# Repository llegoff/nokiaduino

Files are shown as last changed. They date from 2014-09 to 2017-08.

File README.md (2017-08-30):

nokiaduino
==========
carte compatible Arduino équipée d'un afficheur de nokia 5110 , 
un clavier 5 touches, un lecteur de carte microSD, un convertisseur DC-DC boost
et des connecteur pour ajouter des capteurs.

*Arduino compatible board provided with a display of nokia 5110,
5 keys keyboard, a microSD card slot, a DC-DC boost converter
and connector to add sensors.*

Schemas
-------
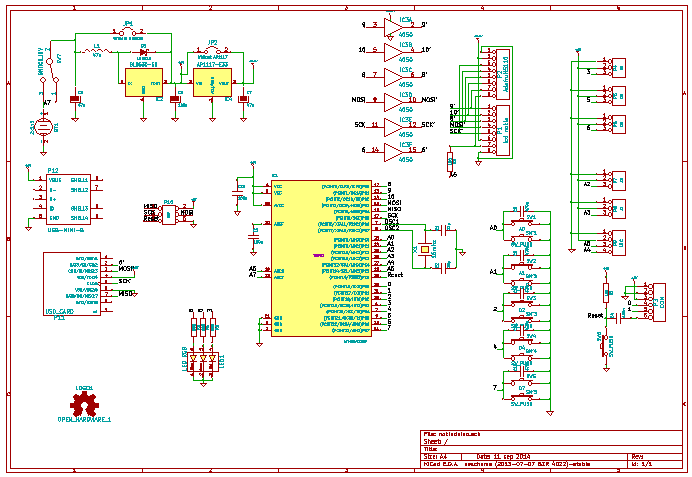
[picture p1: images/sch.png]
sch

nokiaduino.pdf

PCB
---
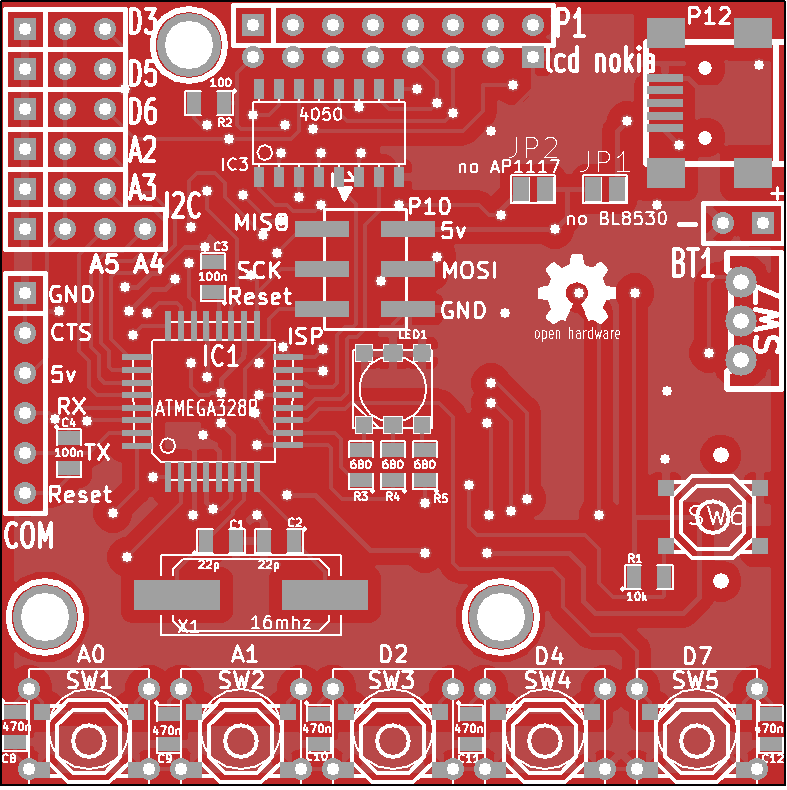
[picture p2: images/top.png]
Top

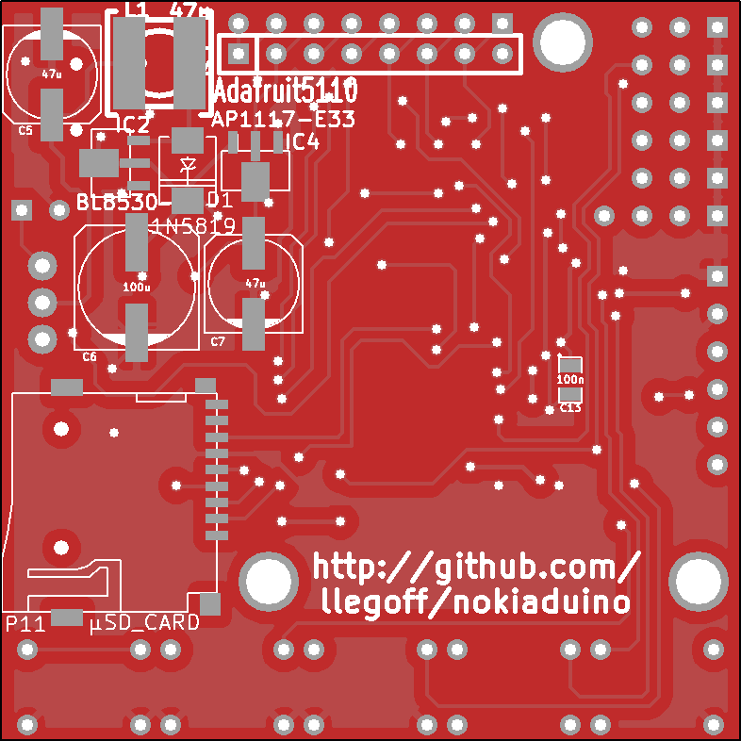
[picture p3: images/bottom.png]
Bottom


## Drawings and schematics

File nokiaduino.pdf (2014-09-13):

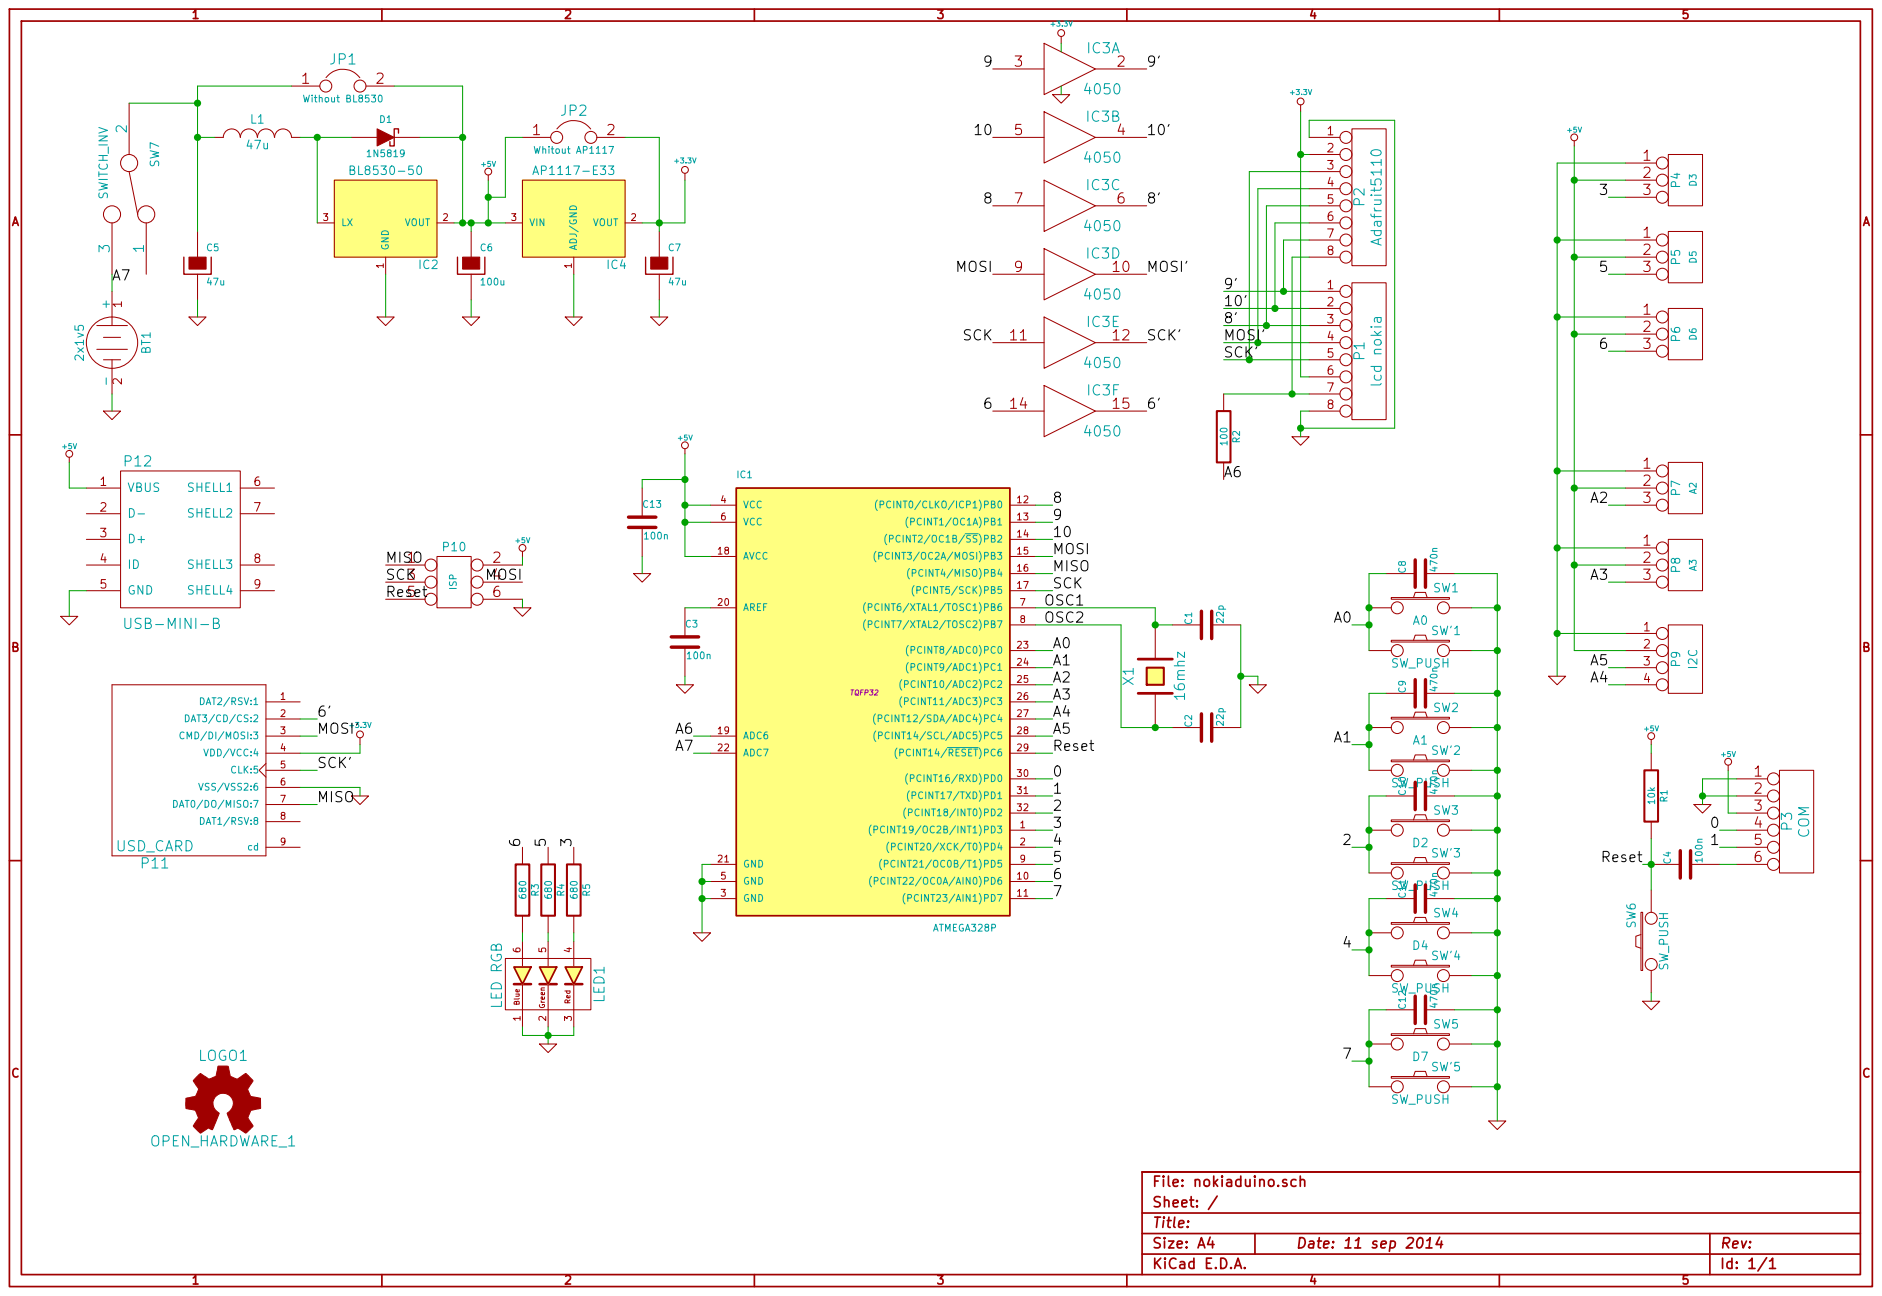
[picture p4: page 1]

Id: 1/1 Title: File: nokiaduino.sch Sheet: /

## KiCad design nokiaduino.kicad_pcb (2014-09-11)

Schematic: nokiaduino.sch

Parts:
BT1: 2x1v5
C1, C2: 22p
C3, C4, C13: 100n
C5, C7: 47u
C6: 100u
C8, C9, C10, C11, C12: 470n
D1: 1N5819
IC1: ATMEGA328P; TQFP32
IC2: BL8530-50
IC3: 4050
IC4: AP1117-E33
JP1: Without BL8530
JP2: Whitout AP1117
L1: 47u
LED1: LED RGB
LOGO1: OPEN_HARDWARE_1
P1: lcd nokia
P2: Adafruit5110
P3: COM
P4: D3
P5: D5
P6: D6
P7: A2
P8: A3
P9: I2C
P10: ISP
P11: USD_CARD
P12: USB-MINI-B
R1: 10k
R2: 100
R3, R4, R5: 680
SW1: A0
SW2: A1
SW3: D2
SW4: D4
SW5: D7
SW6: SW_PUSH
SW7: SWITCH_INV
SW'1, SW'2, SW'3, SW'4, SW'5: SW_PUSH
X1: 16mhz

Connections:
+3.3V: C7.1, IC3.1 (VCC), IC4.2 (VOUT), JP2.2, P1.6, P2.2, P11.4
+5V: C6.1, C13.1, D1.2 (K), IC1.4 (VCC), IC1.6 (VCC), IC1.18 (AVCC), IC2.2 (VOUT), IC4.3 (VIN), JP1.2, JP2.1, P3.3, P4.2 (PM), P5.2 (PM), P6.2 (PM), P7.2 (PM), P8.2 (PM), P9.2, P10.2, P12.1 (VBUS), R1.1
/0: IC1.30 ((PCINT16/RXD)PD0), P3.4
/1: IC1.31 ((PCINT17/TXD)PD1), P3.5
/2: C10.1, IC1.32 ((PCINT18/INT0)PD2), SW3.1, SW'3.1
/3: IC1.1 ((PCINT19/OC2B/INT1)PD3), P4.3, R5.1
/4: C11.1, IC1.2 ((PCINT20/XCK/T0)PD4), SW4.1, SW'4.1
/5: IC1.9 ((PCINT21/OC0B/T1)PD5), P5.3, R4.1
/6: IC1.10 ((PCINT22/OC0A/AIN0)PD6), IC3.14, P6.3, R3.1
/6': IC3.15, P11.2
/7: C12.1, IC1.11 ((PCINT23/AIN1)PD7), SW5.1, SW'5.1
/8: IC1.12 ((PCINT0/CLKO/ICP1)PB0), IC3.7
/8': IC3.6, P1.3, P2.5
/9: IC1.13 ((PCINT1/OC1A)PB1), IC3.3
/9': IC3.2, P1.1, P2.7
/10: IC1.14 ((PCINT2/OC1B/~SS~)PB2), IC3.5
/10': IC3.4, P1.2, P2.6
/A0: C8.1, IC1.23 ((PCINT8/ADC0)PC0), SW1.1, SW'1.1
/A1: C9.1, IC1.24 ((PCINT9/ADC1)PC1), SW2.1, SW'2.1
/A2: IC1.25 ((PCINT10/ADC2)PC2), P7.3
/A3: IC1.26 ((PCINT11/ADC3)PC3), P8.3
/A4: IC1.27 ((PCINT12/SDA/ADC4)PC4), P9.4
/A5: IC1.28 ((PCINT14/SCL/ADC5)PC5), P9.3
/A6: IC1.19 (ADC6), R2.2
/A7: BT1.1 (+), IC1.22 (ADC7), SW7.3
/MISO: IC1.16 ((PCINT4/MISO)PB4), P10.1, P11.7
/MOSI: IC1.15 ((PCINT3/OC2A/MOSI)PB3), IC3.9, P10.4
/MOSI': IC3.10, P1.4, P2.4, P11.3
/OSC1: C1.1, IC1.7 ((PCINT6/XTAL1/TOSC1)PB6), X1.2
/OSC2: C2.1, IC1.8 ((PCINT7/XTAL2/TOSC2)PB7), X1.1
/Reset: C4.1, IC1.29 ((PCINT14/~RESET~)PC6), P10.5, R1.2, SW6.2
/SCK: IC1.17 ((PCINT5/SCK)PB5), IC3.11, P10.3
/SCK': IC3.12, P1.5, P2.3, P11.5
GND: BT1.2 (-), C1.2, C2.2, C3.2, C5.2, C6.2, C7.2, C8.2, C9.2, C10.2, C11.2, C12.2, C13.2, IC1.3 (GND), IC1.5 (GND), IC1.21 (GND), IC2.1 (GND), IC3.8 (VSS), IC4.1 (ADJ/GND), LED1.1 (KB), LED1.2 (KG), LED1.3 (KR), P1.8, P2.1, P3.1, P3.2, P4.1, P5.1, P6.1, P7.1, P8.1, P9.1, P10.6, P11.6, P12.5 (GND), SW1.2, SW2.2, SW3.2, SW4.2, SW5.2, SW6.1, SW'1.2, SW'2.2, SW'3.2, SW'4.2, SW'5.2
unnamed: C5.1, JP1.1, L1.1, SW7.2
unnamed: C4.2, P3.6
unnamed: D1.1 (A), IC2.3 (LX), L1.2
unnamed: LED1.5 (AG), R4.2
unnamed: LED1.6 (AB), R3.2
unnamed: LED1.4 (AR), R5.2
unnamed: C3.1, IC1.20 (AREF)
unnamed: P1.7, P2.8, R2.1

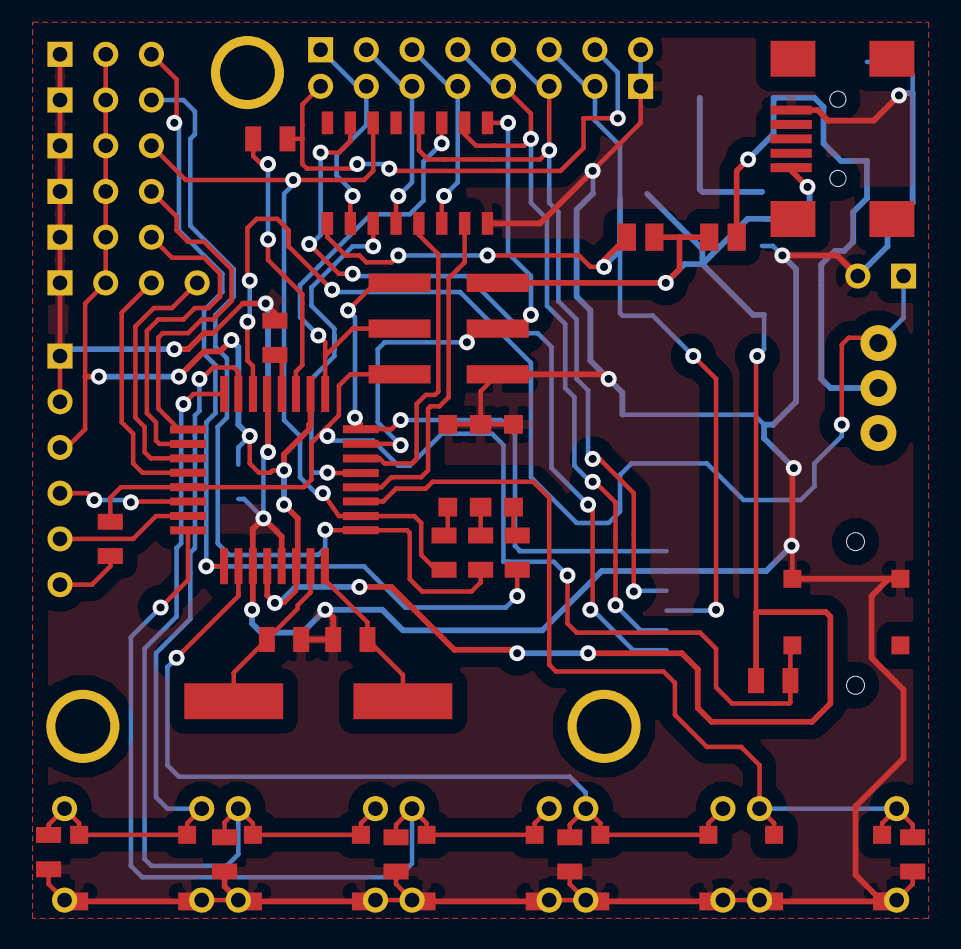
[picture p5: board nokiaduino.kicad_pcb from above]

Board: 2 copper layers, 57 parts (0 on the bottom side), 42 nets.

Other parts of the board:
1PIN, 1PIN#2, 1PIN#3: P***; 1pin

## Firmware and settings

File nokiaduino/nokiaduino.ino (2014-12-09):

#include <dht.h>
#include <SPI.h>
#include <Adafruit_GFX.h>
#include <Adafruit_PCD8544.h>
#include <RTClib.h>
#include <Wire.h>
#include <SD.h>


#define DHT22_PIN 3
#define SW_PIN 5
 Adafruit_PCD8544 display = Adafruit_PCD8544(8, 10, 9);
 RTC_Millis RTC;
 dht DHT;
 unsigned long time;
 unsigned long aff_time;
 unsigned long SD_time;
 unsigned long SW_time;
 boolean sw_compteur = LOW;
 boolean prev_sw_compteur = LOW;
 boolean SD_OK = LOW;
 int compteur = 0;
 int temperature = 0;
 int humidite = 0;
 int correction = 0;
 float alim = 3.3;

static const unsigned char PROGMEM symbSDOK[] =
{ B11111100, 
  B10000010,
  B10000001, 
  B10000001,
  B10000001,
  B10000001,
  B11111111,
};

static const unsigned char PROGMEM symbSDKO[] =
{ B11111100, 
  B11111110,
  B11111111, 
  B11111111,
  B11111111,
  B11111111,
  B11111111,
};

static const unsigned char PROGMEM symbT[] =
{ B00111000, 
  B01000100,
  B01000100, 
  B01000100,
  B00111000,
  B00000000,
  B00111100,
  B01000010,
  B10000000,
  B10000000,
  B10000000,
  B10000000,
  B01000010,
  B00111100 };

static const unsigned char PROGMEM symbH[] =
{ B01100010, 
  B10010100,
  B01101000, 
  B00010110,
  B00101001,
  B01000110,
  B00000000,
  B00010000,
  B00010000,
  B00010000,
  B00101000,
  B01000100,
  B01000100,
  B00111000};

 
void setup() {
  // put your setup code here, to run once:
  pinMode(SW_PIN,INPUT_PULLUP);
  display.begin();
  display.setContrast(55);
  display.display(); // show splashscreen
  display.clearDisplay();   // clears the screen and buffer
  RTC.begin(DateTime(__DATE__, __TIME__));
  SD_OK = SD.begin(6);
  delay(2000);
  aff_time=millis();
  SD_time=aff_time;
  SW_time=SD_time;
}

void loop() {
  time=millis();
  if (time > aff_time + 1000) {
    display.clearDisplay();
    niveauPile();
    Temp();
    dateEtHeure();
//    disp_compteur();
    display.display();
    aff_time = aff_time + 1000;
  }
  if (time > SD_time + 90000) {
    datalogger();
    SD_time=SD_time + 90000;
  }
  comptage();
}

void dateEtHeure() {
  DateTime now =RTC.now();
  display.setTextSize(1);
  display.setTextColor(BLACK);
  display.setCursor(0,0);
  display.print(now.day());
  display.print('/');
  display.print(now.month());
  display.print('/');
  display.print(now.year());
  display.setTextSize(1);
  display.setTextColor(BLACK);
  display.setCursor(6,8);
  display.print(now.hour());
  display.print(':');
  display.print(now.minute());
  display.print(':');
  display.print(now.second());
}

void datalogger() {
  DateTime now =RTC.now();
  SD_OK = SD.begin(6);
  String chaine = "T";
  int i=now.year()-2000;
  if (i<10) chaine = chaine + "0";
  chaine = chaine + String(i);
  i=now.month();
  if (i<10) chaine = chaine + "0";
  chaine = chaine + String(i);
  i=now.day();
  if (i<10) chaine = chaine + "0";
  chaine = chaine + String(i);
  chaine = chaine + ".csv";
  if (SD_OK) {
    i=now.hour();
    chaine = String(i);
    i=now.minute();
    if (i<10) chaine = chaine + "0";
    chaine = chaine + String(i);
    chaine = chaine + ";";
    chaine = chaine + String(temperature);
    chaine = chaine + ";";
    chaine = chaine + String(humidite);
    File fichier = SD.open(chaine , FILE_WRITE);
    if (fichier.size()=0) fichier.println("Heure;Temperature;Humidite");
    else fichier.seek(fichier.size());
    fichier.println(chaine);
    fichier.close;
    }
  }
}

void comptage() {
  sw_compteur=!digitalRead(SW_PIN);
  if (sw_compteur != prev_sw_compteur) {
    if (millis()>(SW_time + 40)){
      if (sw_compteur==HIGH) compteur++;
      prev_sw_compteur=sw_compteur;
      SW_time=millis();
    }
  } 
}

void disp_compteur() {
  display.setTextSize(2);
  display.setTextColor(BLACK);
  display.setCursor(10,16);
  display.print(compteur);
}


void niveauPile(){
  float bat= (float(analogRead(A7))*alim)/1024;
  display.drawRect(65,0,18,7,BLACK);
  display.drawRect(83,2,1,3,BLACK);
  if (bat>2) display.drawRect(67,2,2,3,BLACK);
  if (bat>2.2) display.drawRect(70,2,2,3,BLACK);
  if (bat>2.4) display.drawRect(73,2,2,3,BLACK);
  if (bat>2.6) display.drawRect(76,2,2,3,BLACK);
  if (bat>2.8) display.drawRect(79,2,2,3,BLACK);
}

void Temp(){
  int chk = DHT.read22(DHT22_PIN);
  switch (chk)
  {
    case DHTLIB_OK:
                display.setTextSize(2);
                display.setTextColor(BLACK);
                display.setCursor(4,32);
                temperature = DHT.temperature - correction;
		display.print((temperature),0);
                display.drawBitmap(28,32, symbT, 8, 14, BLACK);
                display.setCursor(46,32);
                humidite = DHT.humidity;
		display.print(humidite,0);
                display.drawBitmap(70,32, symbH, 8, 14, BLACK);
		break;
    case DHTLIB_ERROR_CHECKSUM: 
                display.setTextSize(1);
                display.setTextColor(BLACK);
                display.setCursor(0,32);
		display.print("Checksum error"); 
		break;
    case DHTLIB_ERROR_TIMEOUT: 
                display.setTextSize(1);
                display.setTextColor(BLACK);
                display.setCursor(0,32);
		display.print("Time out error"); 
		break;
    default: 
                display.setTextSize(1);
                display.setTextColor(BLACK);
                display.setCursor(0,32);
		display.print("Unknown error"); 
		break;
  }
}
